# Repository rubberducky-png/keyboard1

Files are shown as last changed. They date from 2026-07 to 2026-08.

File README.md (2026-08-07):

<center>

# rektek keyboard1: 81-Key Mechanical Keyboard

A fully custom 81-key mechanical keyboard designed by me, including the PCB, case, firmware, and assembly. This project was built to learn the complete keyboard design process while creating a functional keyboard.

Funded With The Macondo Program

## Features

- Custom PCB designed from scratch
- Hot-swappable MX-compatible switches
- QMK firmware support
- Screw-in stabilizers
- 3D printed two-piece tray mount case
- 8° typing angle for improved ergonomics
- bluetooth capabilites (connect to another screen while plugged into one)
  
## Why I Built It

I've always been interested in how things work, so when I was looking for a project I happened to glance at my hands, with my keyboard right underneath. Instead of buying an existing keyboard, I decided to design every  component like the PCB myself.

## Design Process

The project began by selecting a 81-key layout that has a lot of function but is also on the smaller side. I then designed the PCB in KiCad, routed all the traces, and added support for hot-swap sockets and USB-C connectivity. After the electronics were complete I designed a simple tray mount in Onshape. The case is made out of two PLA printed pieces and includes a 7° typing angle for a more comfortable typing experience. Because of small bed size I will have to print them in pieces.

Finally, the keyboard is programmed using qmk firmware.

## Challenges

Some of the biggest challenges included:

- Learning PCB routing and keyboard matrix design
- Designing a printable case that was able to support the pcb well
- Ensuring all mounting points aligned correctly

## Files:
I apologize for the mess, when I put my files into folders the larger ones kept deleting themselves.

## Images and Renders!

### Matrix Schematic



### OnShape Render

#### Case


### PCB


### Assembly

I apologize again for the semi-completed assembly, my document on Onshape couldn't take all of the lag from the amount of parts and started to kick me off of the document every time I went to import something.

## Sketch


## Bill of Materials (BOM)

| # | Component | Qty. | Cost |
|---:|---|---:|---:|
| 1 | Gateron Milky Yellow Pro Switches | 90 | $28.00 |
| 2 | 1N4148 Diodes | 82 | $2.46 |
| 3 | Cherry-style Stabilizer Set | 1 | $6.00 |
| 4 | ALPS EC11E Rotary Encoder | 1 | $2.75 |
| 5 | Raspberry Pi Pico | 1 | $3.95 |
| 6 | RN4871U-V/RM118 Bluetooth Module | 1 | $7.65 |
| 7 | 0805 Resistors | 2 | $0.04 |
| 8 | 0603 100nF Capacitor | 1 | $0.02 |
| 9 | 0805 Status LED | 1 | $0.05 |
| 10 | M2 Case Screws | 12 | $1.20 |
| 11 | M2 Heat-Set Inserts | 4 | $0.60 |
| 12 | JLCPCB PCB Fabrication | 5 | $27.20 |
| 13 | Glorious GPBT Basics Keycaps | 1 | $17.49 |
| 14 | USB-C to Micro-USB Cable | 1 | $6.00 |
| 15 | PETG/PLA Filament | 1 | $12.00 |
| 16 | JLCPCB DHL Express Shipping | 1 | $27.96 |
| | **Total** | | **$144.42** |
btw I also dont have a soldering iron but Im hoping I have enough fruits to get the pinecil

## Shoutout hackclub and the macondo program

</center>

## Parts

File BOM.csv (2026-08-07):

SI No. | Name | Notes | Quantity | Price Per Unit | Cost | Total | Link
1 | Gateron Milky Yellow Pro Switches | MX-compatible 5-pin linear switches; 2x45-pack | 90 | 0.31 | 28.00 |  | https://www.gateron.co/products/gateron-ks-3-milky-pro-switch-set
2 | 1N4148 Diodes | Through-hole switching diodes for keyboard matrix | 82 | 0.03 | 2.46 |  | https://www.amazon.com/s?k=120PCS+1N4148+Rectifier+Diodes+100V+DO-35
3 | Cherry-style Stabilizer Set | 2x 2.25u, 1x 2u, 1x 6.25u | 1 | 6.00 | 6.00 |  | https://www.amazon.com/s?k=Cherry+PCB+Mount+Stabilizer+Set+6.25u+2u
4 | ALPS EC11E15204A3 Rotary Encoder | Through-hole EC11 encoder with integrated push switch; matches PCB EC11E footprint | 1 | 2.75 | 2.75 |  | https://www.newark.com/alps-alpine/ec11e15204a3/encoder-vertical-11mm-30det/dp/75T6719
5 | Raspberry Pi Pico | RP2040 microcontroller board | 1 | 3.95 | 3.95 |  | https://www.pishop.us/product/raspberry-pi-pico/
6 | RN4871U-V/RM118 Bluetooth Module | Bluetooth 5.0 BLE UART module; current DigiKey price | 1 | 7.65 | 7.65 |  | https://www.digikey.com/en/products/detail/microchip-technology/RN4871U-V-RM118/6130475
7 | 0805 Resistors | 330Ω and 10kΩ resistors | 2 | 0.02 | 0.04 |  | https://www.digikey.com/en/products/filter/chip-resistor-surface-mount/52
8 | 0603 100nF Capacitor | Ceramic decoupling capacitor | 1 | 0.02 | 0.02 |  | https://www.digikey.com/en/products/filter/ceramic-capacitors/60
9 | 0805 Status LED | 0805 indicator LED | 1 | 0.05 | 0.05 |  | https://www.digikey.com/en/products/filter/led-indication-discrete/105
10 | M2 Case Screws | 12 total M2 screws for PCB/case assembly; consolidated from previous screw lines | 12 | 0.10 | 1.20 |  | https://www.amazon.com/s?k=M2+screw+kit
11 | M2 Heat-Set Inserts | Brass threaded inserts for 3D-printed case | 4 | 0.15 | 0.60 |  | https://partsbuilt.com/m2-heat-set-thread-insert-3mm-wide-3mm-long-4-pack/
12 | PCB Fabrication (313.25×154.70mm 2-Layer) | 5 PCBs; JLCPCB manufacturing + engineering fee from actual quote | 5 | 5.44 | 27.20 |  | https://jlcpcb.com
13 | Glorious GPBT Basics Keycap Set | 131-key doubleshot PBT keycap set compatible with 75% MX-style keyboards | 1 | 17.49 | 17.49 |  | https://www.microcenter.com/product/684612/glorious-gpbt-basics-keycaps-classic-black
14 | USB-C to Micro-USB Cable | Programming/data cable | 1 | 6.00 | 6.00 |  | https://www.amazon.com/s?k=Cable+Matters+USB+C+to+Micro+USB+Cable+3.3ft
15 | PETG/PLA Filament | Filament for printing keyboard case | 1 | 12.00 | 12.00 |  | https://www.amazon.com/s?k=PETG+1.75mm+filament
16 | JLCPCB DHL Express Shipping | Shipping for 5 PCBs from JLCPCB | 1 | 27.96 | 27.96 |  | https://jlcpcb.com
 |  |  |  |  |  | 144.42

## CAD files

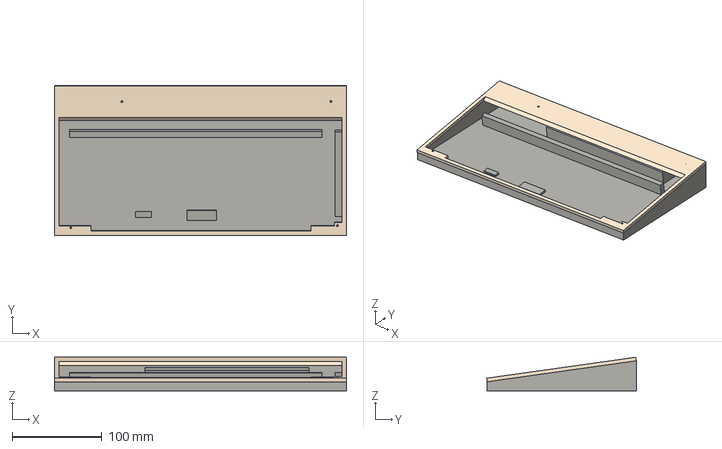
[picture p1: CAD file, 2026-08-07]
CAD/CompleteCase.step
325.0 x 166.7 x 37.3 mm

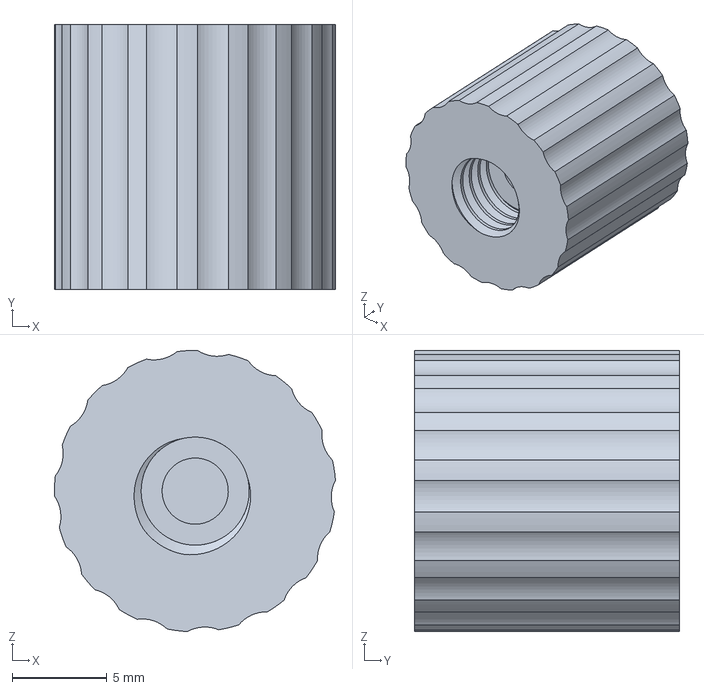
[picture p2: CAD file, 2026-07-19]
CAD/rotary knob.step
14.9 x 14.0 x 14.9 mm

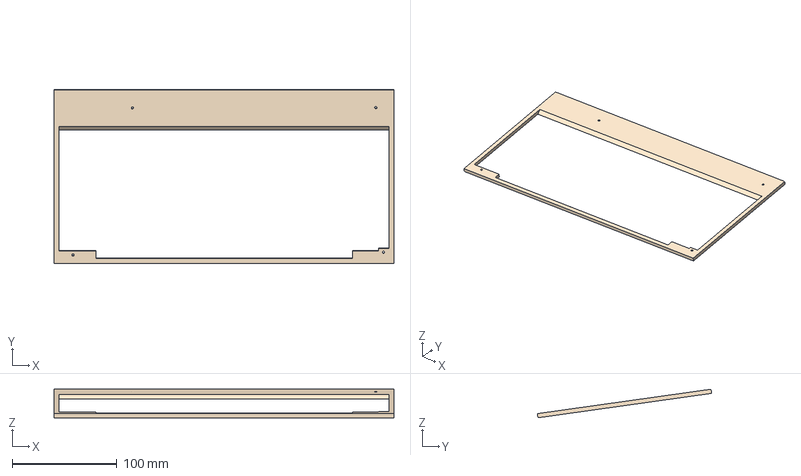
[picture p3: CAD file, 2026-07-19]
CAD/keyboard top.step
325.0 x 166.7 x 27.3 mm

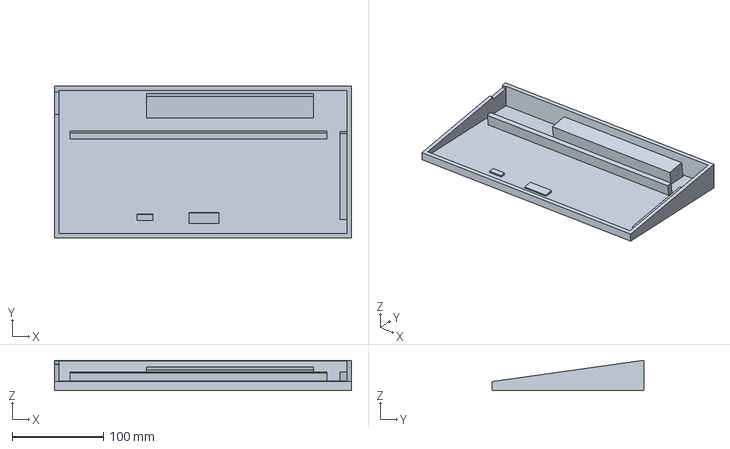
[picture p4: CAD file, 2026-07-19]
CAD/keyboard bottom.step
325.0 x 166.1 x 33.3 mm

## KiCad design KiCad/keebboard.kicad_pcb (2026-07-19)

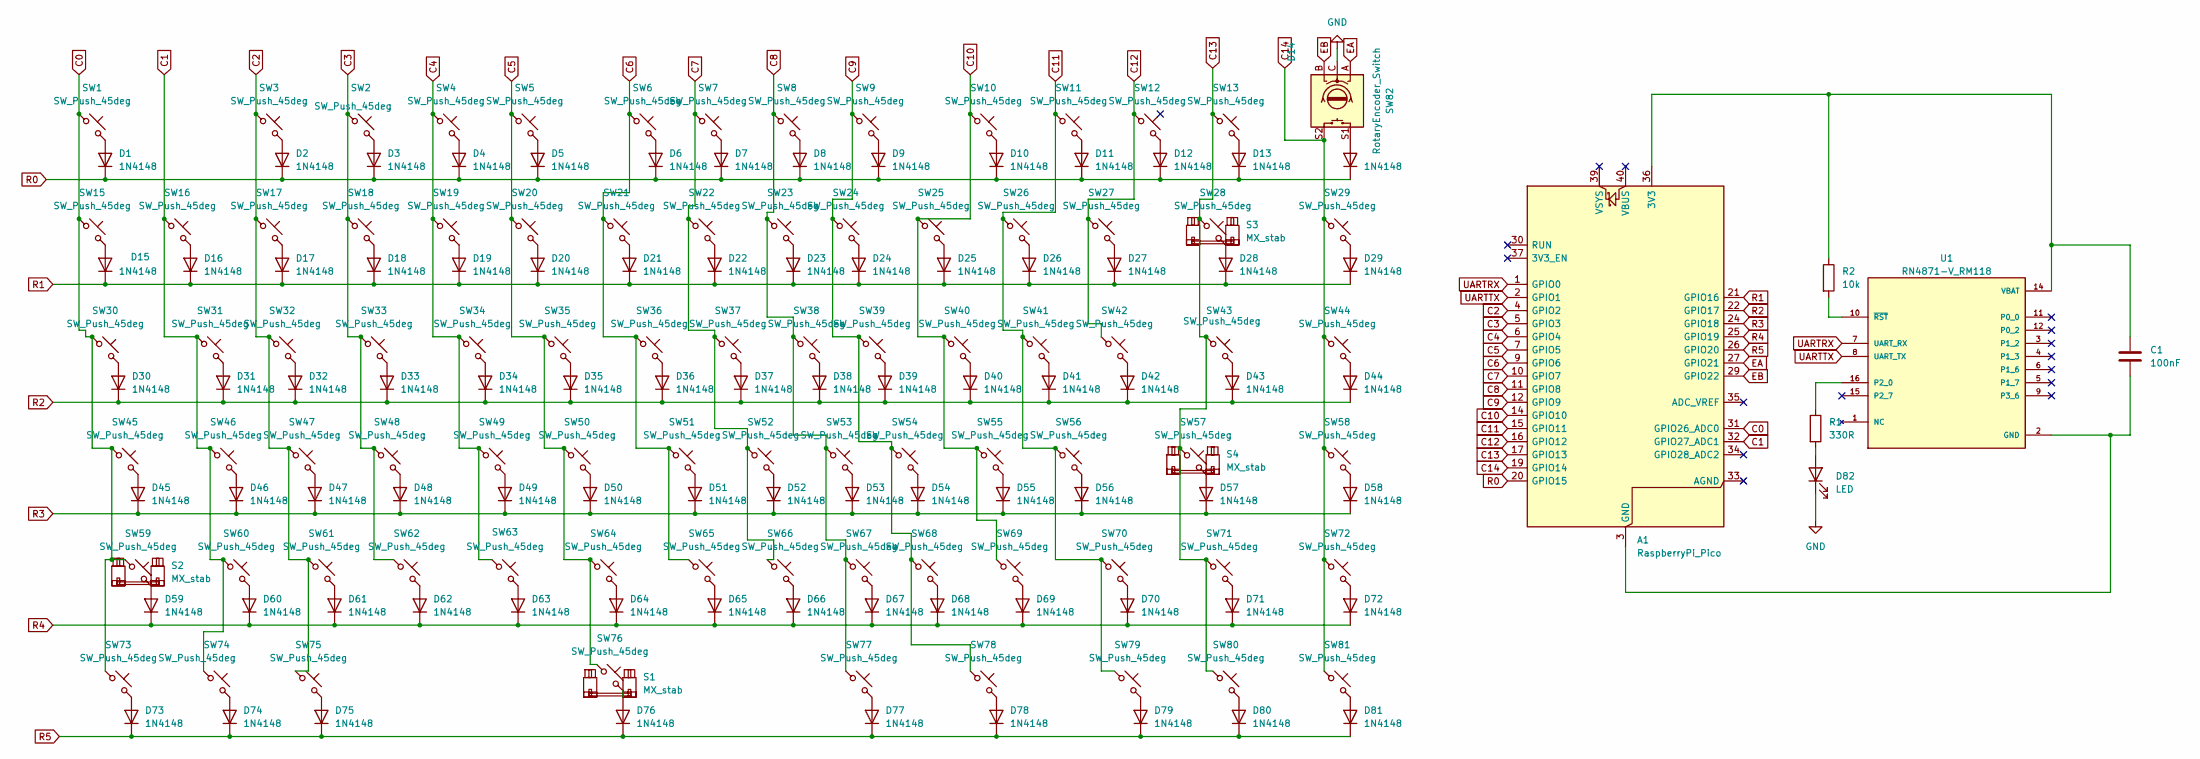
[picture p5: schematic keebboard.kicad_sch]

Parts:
A1: RaspberryPi_Pico; RaspberryPi_Pico_Common_Unspecified
C1: 100nF; C_0603_1608Metric_Pad1.08x0.95mm_HandSolder
D1, D2, D3, D4, D5, D6, D7, D8, D9, D10, D11, D12, D13, D14, D15, D16, D17, D18, D19, D20, D21, D22, D23, D24, D25, D26, D27, D28, D29, D30, D31, D32, D33, D34, D35, D36, D37, D38, D39, D40, D41, D42, D43, D44, D45, D46, D47, D48, D49, D50, D51, D52, D53, D54, D55, D56, D57, D58, D59, D60, D61, D62, D63, D64, D65, D66, D67, D68, D69, D70, D71, D72, D73, D74, D75, D76, D77, D78, D79, D80, D81: 1N4148; D_DO-35_SOD27_P7.62mm_Horizontal
D82: LED; LED_0805_2012Metric
R1: 330R; R_0805_2012Metric
R2: 10k; R_0805_2012Metric
S1, S2, S3, S4: MX_stab; STAB_MX_P_6.25u
SW1, SW2, SW3, SW4, SW5, SW6, SW7, SW8, SW9, SW10, SW11, SW12, SW13, SW15, SW16, SW17, SW18, SW19, SW20, SW21, SW22, SW23, SW24, SW25, SW26, SW27, SW29, SW31, SW32, SW33, SW34, SW35, SW36, SW37, SW38, SW39, SW40, SW41, SW42, SW44, SW46, SW47, SW48, SW49, SW50, SW51, SW52, SW53, SW54, SW55, SW56, SW58, SW60, SW61, SW62, SW63, SW64, SW65, SW66, SW67, SW68, SW69, SW71, SW72, SW79, SW80, SW81: SW_Push_45deg; SW_Cherry_MX_1.00u_PCB
SW28: SW_Push_45deg; SW_Cherry_MX_2.00u_PCB
SW30, SW78: SW_Push_45deg; SW_Cherry_MX_1.50u_PCB
SW43, SW45, SW70: SW_Push_45deg; SW_Cherry_MX_1.75u_PCB
SW57, SW59: SW_Push_45deg; SW_Cherry_MX_2.25u_PCB
SW73, SW74, SW75, SW77: SW_Push_45deg; SW_Cherry_MX_1.25u_PCB
SW76: SW_Push_45deg; SW_Cherry_MX_6.25u_PCB
SW82: RotaryEncoder_Switch; RotaryEncoder_Alps_EC11E-Switch_Vertical_H20mm
U1: RN4871-V_RM118; XCVR_RN4871-V_RM118; PARTREV E

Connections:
C0: A1.31 (GPIO26_ADC0), SW1.1, SW15.1, SW30.1, SW45.1, SW59.1, SW73.1
C1: A1.32 (GPIO27_ADC1), SW16.1, SW31.1, SW46.1, SW60.1, SW74.1
C2: A1.4 (GPIO2), SW3.1, SW17.1, SW32.1, SW47.1, SW61.1, SW75.1
C3: A1.5 (GPIO3), SW2.1, SW18.1, SW33.1, SW48.1, SW62.1
C4: A1.6 (GPIO4), SW4.1, SW19.1, SW34.1, SW49.1, SW63.1
C5: A1.7 (GPIO5), SW5.1, SW20.1, SW35.1, SW50.1, SW64.1, SW76.1
C6: A1.9 (GPIO6), SW6.1, SW21.1, SW36.1, SW51.1, SW65.1
C7: A1.10 (GPIO7), SW7.1, SW22.1, SW37.1, SW52.1, SW66.1
C8: A1.11 (GPIO8), SW8.1, SW23.1, SW38.1, SW53.1, SW67.1, SW77.1
C9: A1.12 (GPIO9), SW9.1, SW24.1, SW39.1, SW54.1, SW68.1, SW78.1
C10: A1.14 (GPIO10), SW10.1, SW25.1, SW40.1, SW55.1, SW69.1
C11: A1.15 (GPIO11), SW11.1, SW26.1, SW41.1, SW56.1, SW70.1, SW79.1
C12: A1.16 (GPIO12), SW12.1, SW27.1, SW42.1
C13: A1.17 (GPIO13), SW13.1, SW28.1, SW43.1, SW57.1, SW71.1, SW80.1
C14: A1.19 (GPIO14), SW29.1, SW44.1, SW58.1, SW72.1, SW81.1, SW82.S2
EA: A1.27 (GPIO21), SW82.A
EB: A1.29 (GPIO22), SW82.B
unnamed: A1.36 (3V3), C1.1, R2.1, U1.14 (VBAT)
unnamed: D1.2 (A), SW1.2
unnamed: D2.2 (A), SW3.2
unnamed: D3.2 (A), SW2.2
unnamed: D4.2 (A), SW4.2
unnamed: D5.2 (A), SW5.2
unnamed: D6.2 (A), SW6.2
unnamed: D7.2 (A), SW7.2
unnamed: D8.2 (A), SW8.2
unnamed: D9.2 (A), SW9.2
unnamed: D10.2 (A), SW10.2
unnamed: D11.2 (A), SW11.2
unnamed: D12.2 (A), SW12.2
unnamed: D13.2 (A), SW13.2
unnamed: D14.2 (A), SW82.S1
unnamed: D15.2 (A), SW15.2
unnamed: D16.2 (A), SW16.2
unnamed: D17.2 (A), SW17.2
unnamed: D18.2 (A), SW18.2
unnamed: D19.2 (A), SW19.2
unnamed: D20.2 (A), SW20.2
unnamed: D21.2 (A), SW21.2
unnamed: D22.2 (A), SW22.2
unnamed: D23.2 (A), SW23.2
unnamed: D24.2 (A), SW24.2
unnamed: D25.2 (A), SW25.2
unnamed: D26.2 (A), SW26.2
unnamed: D27.2 (A), SW27.2
unnamed: D28.2 (A), SW28.2
unnamed: D29.2 (A), SW29.2
unnamed: D30.2 (A), SW30.2
unnamed: D31.2 (A), SW31.2
unnamed: D32.2 (A), SW32.2
unnamed: D33.2 (A), SW33.2
unnamed: D34.2 (A), SW34.2
unnamed: D35.2 (A), SW35.2
unnamed: D36.2 (A), SW36.2
unnamed: D37.2 (A), SW37.2
unnamed: D38.2 (A), SW38.2
unnamed: D39.2 (A), SW39.2
unnamed: D40.2 (A), SW40.2
unnamed: D41.2 (A), SW41.2
unnamed: D42.2 (A), SW42.2
unnamed: D43.2 (A), SW43.2
unnamed: D44.2 (A), SW44.2
unnamed: D45.2 (A), SW45.2
unnamed: D46.2 (A), SW46.2
unnamed: D47.2 (A), SW47.2
unnamed: D48.2 (A), SW48.2
unnamed: D49.2 (A), SW49.2
unnamed: D50.2 (A), SW50.2
unnamed: D51.2 (A), SW51.2
unnamed: D52.2 (A), SW52.2
unnamed: D53.2 (A), SW53.2
unnamed: D54.2 (A), SW54.2
unnamed: D55.2 (A), SW55.2
unnamed: D56.2 (A), SW56.2
unnamed: D57.2 (A), SW57.2
unnamed: D58.2 (A), SW58.2
unnamed: D59.2 (A), SW59.2
unnamed: D60.2 (A), SW60.2
unnamed: D61.2 (A), SW61.2
unnamed: D62.2 (A), SW62.2
unnamed: D63.2 (A), SW63.2
unnamed: D64.2 (A), SW64.2
unnamed: D65.2 (A), SW65.2
unnamed: D66.2 (A), SW66.2
unnamed: D67.2 (A), SW67.2
unnamed: D68.2 (A), SW68.2
unnamed: D69.2 (A), SW69.2
unnamed: D70.2 (A), SW70.2
unnamed: D71.2 (A), SW71.2
unnamed: D72.2 (A), SW72.2
unnamed: D73.2 (A), SW73.2
unnamed: D74.2 (A), SW74.2
unnamed: D75.2 (A), SW75.2
unnamed: D76.2 (A), SW76.2
unnamed: D77.2 (A), SW77.2
unnamed: D78.2 (A), SW78.2
unnamed: D79.2 (A), SW79.2
unnamed: D80.2 (A), SW80.2
unnamed: D81.2 (A), SW81.2
unnamed: D82.2 (A), R1.2
unnamed: R1.1, U1.16 (P2_0)
unnamed: R2.2, U1.10 (~RST)
R0: A1.20 (GPIO15), D1.1 (K), D2.1 (K), D3.1 (K), D4.1 (K), D5.1 (K), D6.1 (K), D7.1 (K), D8.1 (K), D9.1 (K), D10.1 (K), D11.1 (K), D12.1 (K), D13.1 (K), D14.1 (K)
R1: A1.21 (GPIO16), D15.1 (K), D16.1 (K), D17.1 (K), D18.1 (K), D19.1 (K), D20.1 (K), D21.1 (K), D22.1 (K), D23.1 (K), D24.1 (K), D25.1 (K), D26.1 (K), D27.1 (K), D28.1 (K), D29.1 (K)
R2: A1.22 (GPIO17), D30.1 (K), D31.1 (K), D32.1 (K), D33.1 (K), D34.1 (K), D35.1 (K), D36.1 (K), D37.1 (K), D38.1 (K), D39.1 (K), D40.1 (K), D41.1 (K), D42.1 (K), D43.1 (K), D44.1 (K)
R3: A1.24 (GPIO18), D45.1 (K), D46.1 (K), D47.1 (K), D48.1 (K), D49.1 (K), D50.1 (K), D51.1 (K), D52.1 (K), D53.1 (K), D54.1 (K), D55.1 (K), D56.1 (K), D57.1 (K), D58.1 (K)
R4: A1.25 (GPIO19), D59.1 (K), D60.1 (K), D61.1 (K), D62.1 (K), D63.1 (K), D64.1 (K), D65.1 (K), D66.1 (K), D67.1 (K), D68.1 (K), D69.1 (K), D70.1 (K), D71.1 (K), D72.1 (K)
R5: A1.26 (GPIO20), D73.1 (K), D74.1 (K), D75.1 (K), D76.1 (K), D77.1 (K), D78.1 (K), D79.1 (K), D80.1 (K), D81.1 (K)
UARTRX: A1.1 (GPIO0), U1.7 (UART_RX)
UARTTX: A1.2 (GPIO1), U1.8 (UART_TX)

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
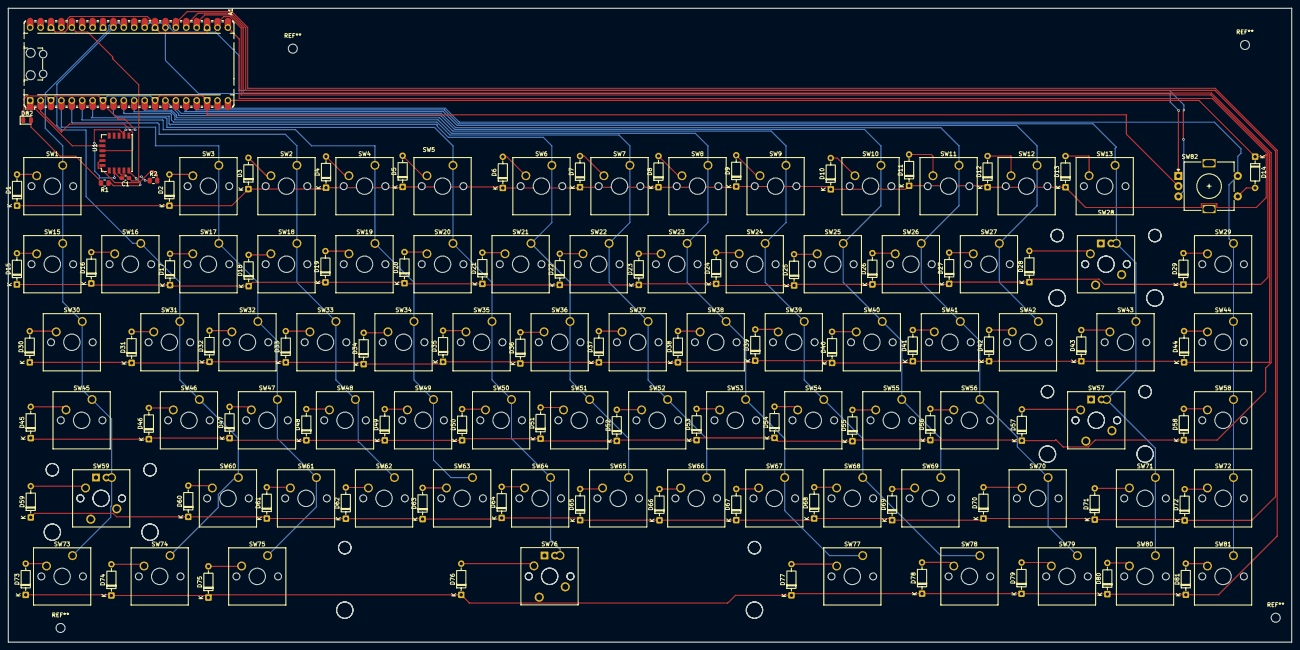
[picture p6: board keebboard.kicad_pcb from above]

Board: 2 copper layers, 313.2 x 154.7 mm, 172 parts (0 on the bottom side), 111 nets.

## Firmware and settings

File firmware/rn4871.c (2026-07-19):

#include "rn4871.h"
#include "hardware/uart.h"
#include "hardware/gpio.h"
#include "pico/time.h"
#include <string.h>

#define RN_UART   uart0
#define RN_TX_PIN 0   // GP0 -> RN4871 UART_RX
#define RN_RX_PIN 1   // GP1 <- RN4871 UART_TX
#define RN_BAUD   115200

static uint8_t pressed_keys[6] = {0};
static uint8_t pressed_modifier = 0;

static void rn_send(const char *cmd) {
    uart_puts(RN_UART, cmd);
    uart_puts(RN_UART, "\r\n");
    sleep_ms(100);
}

void rn4871_init(void) {
    uart_init(RN_UART, RN_BAUD);
    gpio_set_function(RN_TX_PIN, GPIO_FUNC_UART);
    gpio_set_function(RN_RX_PIN, GPIO_FUNC_UART);
}

void rn4871_configure_hid(void) {
    uart_puts(RN_UART, "$$$");
    sleep_ms(100);
    rn_send("+");
    rn_send("SF,2");         
    sleep_ms(200);
    uart_puts(RN_UART, "$$$");
    sleep_ms(100);
    rn_send("+");
    rn_send("SN,keebboard");
    rn_send("SDA,03C1");      
    rn_send("R,1"); 
    sleep_ms(500);
}

void rn4871_send_report(uint8_t modifier, const uint8_t keys[6]) {
    (void) modifier;
    (void) keys;
}

void rn4871_update_key(uint16_t keycode, bool pressed) {
    bool changed = false;

    if (pressed) {
        for (int i = 0; i < 6; i++) {
            if (pressed_keys[i] == 0) {
                pressed_keys[i] = (uint8_t) keycode;
                changed = true;
                break;
            }
        }
    } else {
        for (int i = 0; i < 6; i++) {
            if (pressed_keys[i] == (uint8_t) keycode) {
                pressed_keys[i] = 0;
                changed = true;
                break;
            }
        }
    }

    if (changed) {
        rn4871_send_report(pressed_modifier, pressed_keys);
    }
}

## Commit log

2026-07-19 Enhance README with Bluetooth note and BOM attachment
    Updated the README to include a note about Bluetooth capabilities and attached the BOM as a separate spreadsheet file.
2026-07-19 Update README with BOM and shoutout sections
2026-07-20 Rename rotary knob.step to CAD/rotary knob.step
    [rotary knob.step]
2026-07-20 Rename keyboard top.step to CAD/keyboard top.step
    [keyboard top.step]
2026-07-20 Rename keyboard bottom.step to CAD/keyboard bottom.step
    [keyboard bottom.step]
2026-07-20 Rename 'Components' section to 'BOM'
    Updated section header from 'Components' to 'BOM' and adjusted formatting.
2026-08-07 Remove PCB section from README
    Removed PCB section from the README.
2026-08-07 Modify Gateron Milky Yellow Pro Switches entry in BOM
    Updated the quantity and price for Gateron Milky Yellow Pro Switches.
    [BOM.csv]
2026-08-07 Update BOM with new quantities and pricing
    Updated quantities and prices for several components, added shipping cost, and adjusted total cost.
    [BOM.csv]
